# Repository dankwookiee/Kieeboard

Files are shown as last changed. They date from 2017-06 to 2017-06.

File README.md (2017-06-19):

# Readme and Disclaimer

OEM Key profiles were measured off of a set of Vortex PBT Doubleshot 104-Key caps. 

Cherry Key Profiles were estimated off of Cherry Corp. datasheets. 

Files were made using Solidworks 2017. 

This readme shows the keys available in each layout pack, and then walks through the process of modifying dimensions on original Solidworks files. 

Each key in each pack is selectable as a configuration within the solidworks part file. 

**No Measurement or Dimension is Guaranteed to be Accurate or Suitable.**

Absolutely no guarantee is made that these models will perform as expected. Use at your own risk. Models are licensed under Creative Commons Attribution 4.0. Please redistribute and/or modify at will. Please respect the open source nature of these files, and do not use them for personal profit or commercial use. 

**Table of Contents**  *generated with [DocToc](http://doctoc.herokuapp.com/)*

- [Readme and Disclaimer](#)
	- [Layout of Keys in Cherry Pack](#layout-of-keys-in-cherry-pack)
	- [Layout of Keys in OEM Pack](#layout-of-keys-in-oem-pack)
	- [Base dimensions](#base-dimensions)
	- [Angle of Key Front](#angle-of-key-front)
	- [Angle of Key Rear](#angle-of-key-rear)
	- [Front and Rear Key Height](#front-and-rear-key-height)
	- [Shape of Cylindrical Top, Front Sketch](#shape-of-cylindrical-top-front-sketch)
	- [Shape of Cylindrical Top, Rear Sketch](#shape-of-cylindrical-top-rear-sketch)
	- [Wall Thickness](#wall-thickness)
	- [Upright Edge Fillets](#upright-edge-fillets)
	- [Top Edge Fillet](#top-edge-fillet)
	- [Stem Dimensions](#stem-dimensions)
	- [Final Touches/Stabilizer Stems](#final-touchesstabilizer-stems)
	- [Dimensions already included in configurations:](#dimensions-already-included-in-configurations)

## Layout of Keys in Cherry Pack

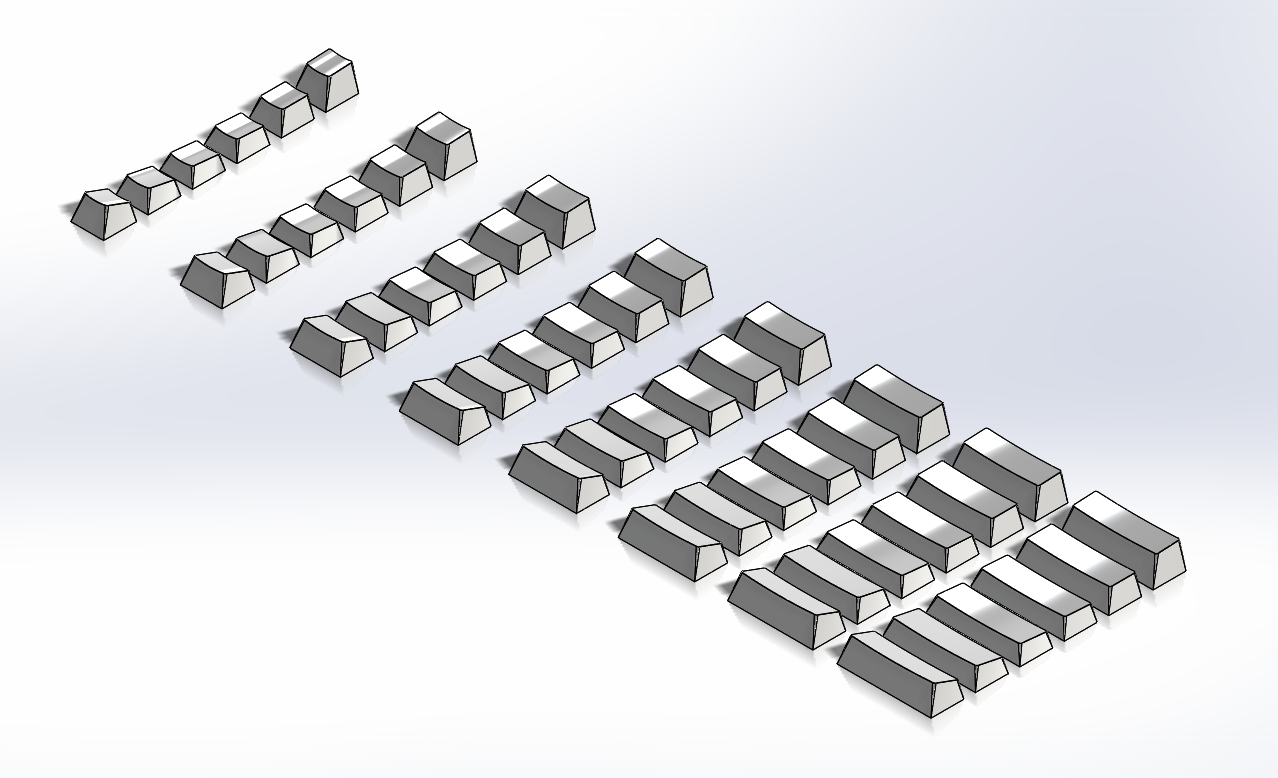
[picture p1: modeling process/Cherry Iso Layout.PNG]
Cherry ISO Layout


## Layout of Keys in OEM Pack

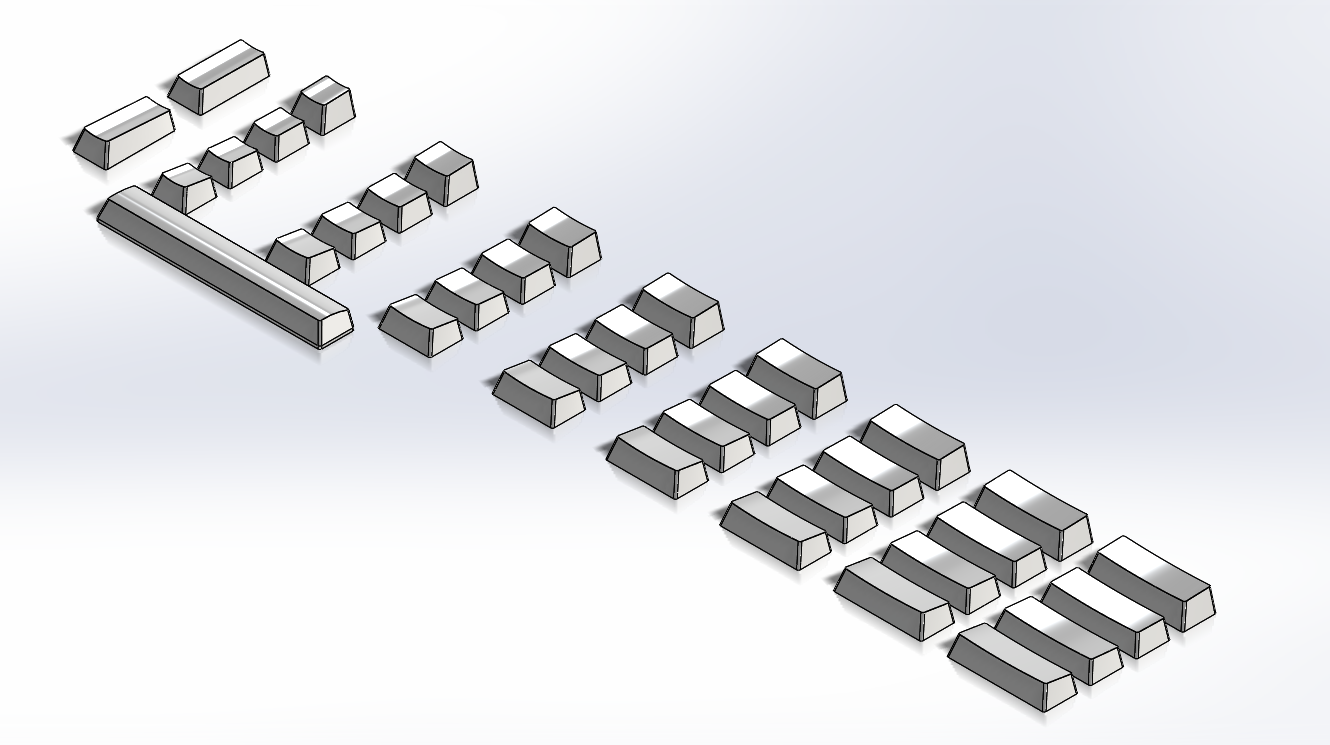
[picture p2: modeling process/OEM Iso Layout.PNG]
OEM ISO Layout


**Modifying Base Dimensions on Wookiee’s Keycaps Files**

## Base dimensions

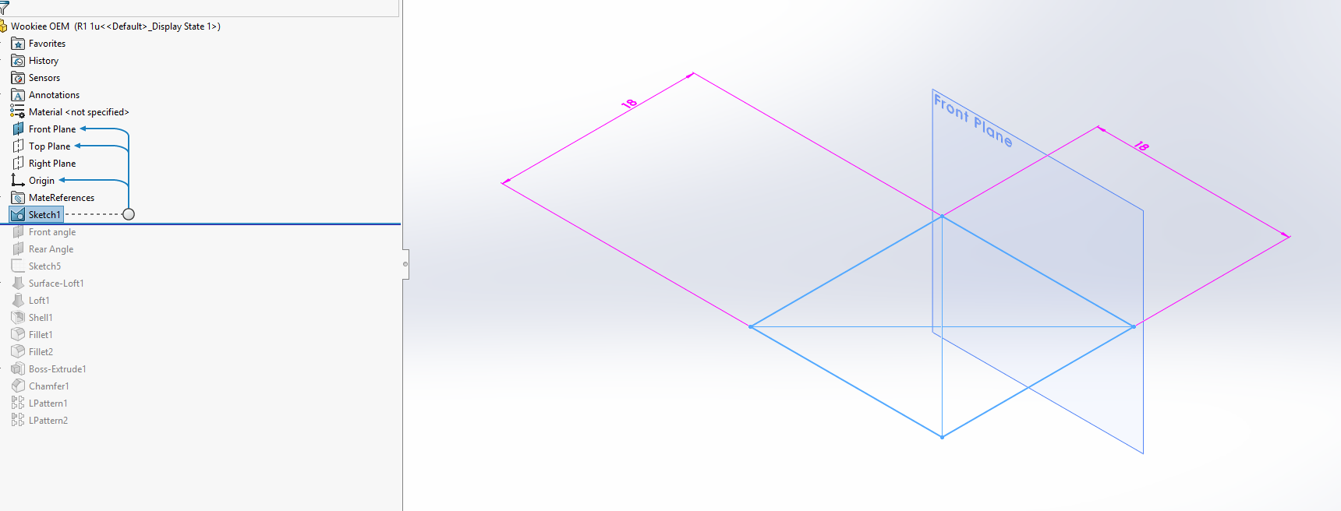
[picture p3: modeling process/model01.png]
Base Dimension Sketch


Base key dimensions are 18x18. Including these dimensions in configurations and design table allows me to switch between any key width and length.

## Angle of Key Front

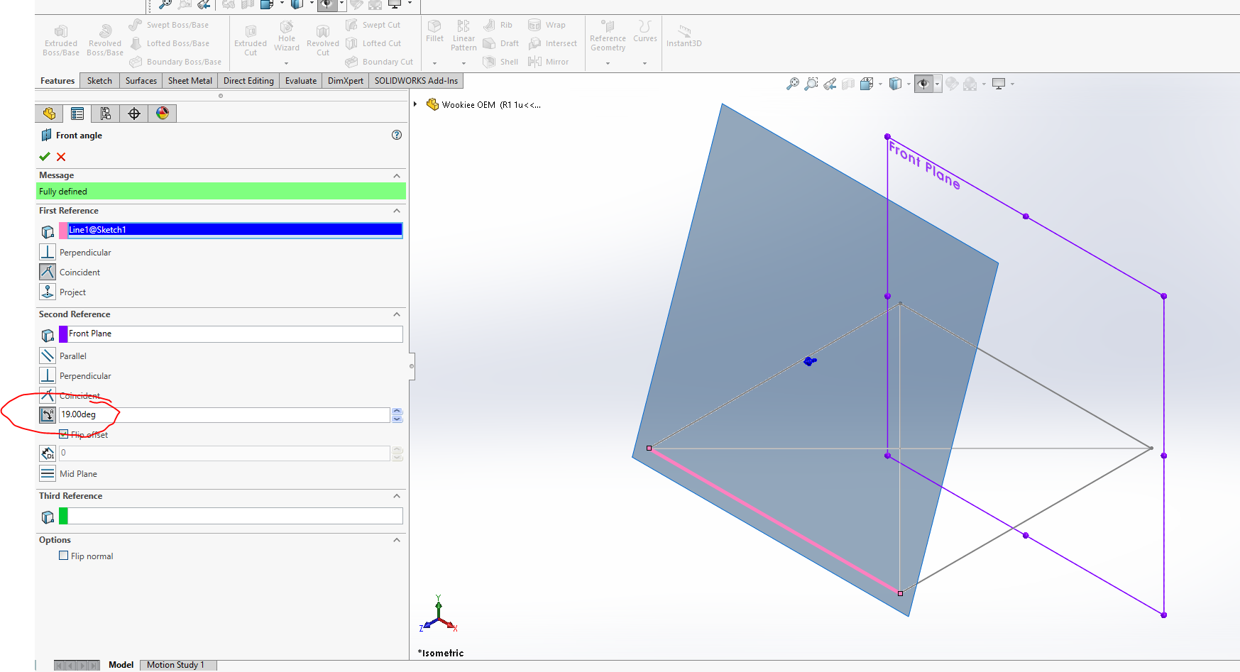
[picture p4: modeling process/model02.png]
Front Angle Sketch


Front plane angle is set coincident with front edge of base, and at an angle. This angle can be adjusted for all configurations, or you can add it to the design table and set different angles for each configuration.
 
## Angle of Key Rear

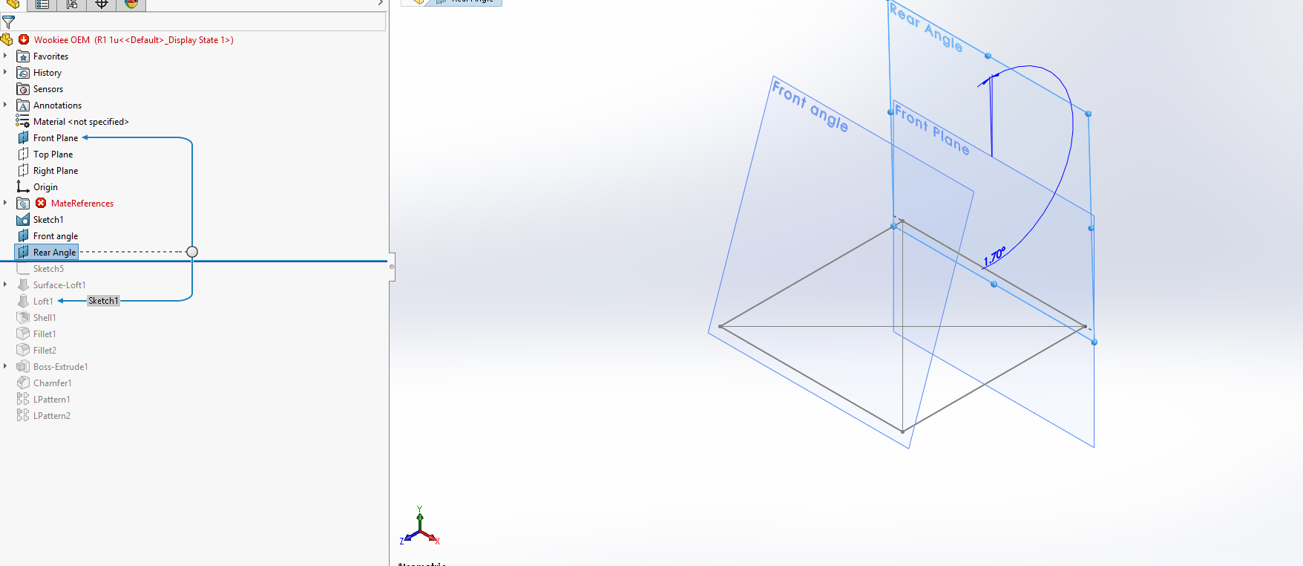
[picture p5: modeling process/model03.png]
Rear Angle Sketch


The angle of the rear plane is set the same way, but references the rear edge of the base sketch. 

## Front and Rear Key Height

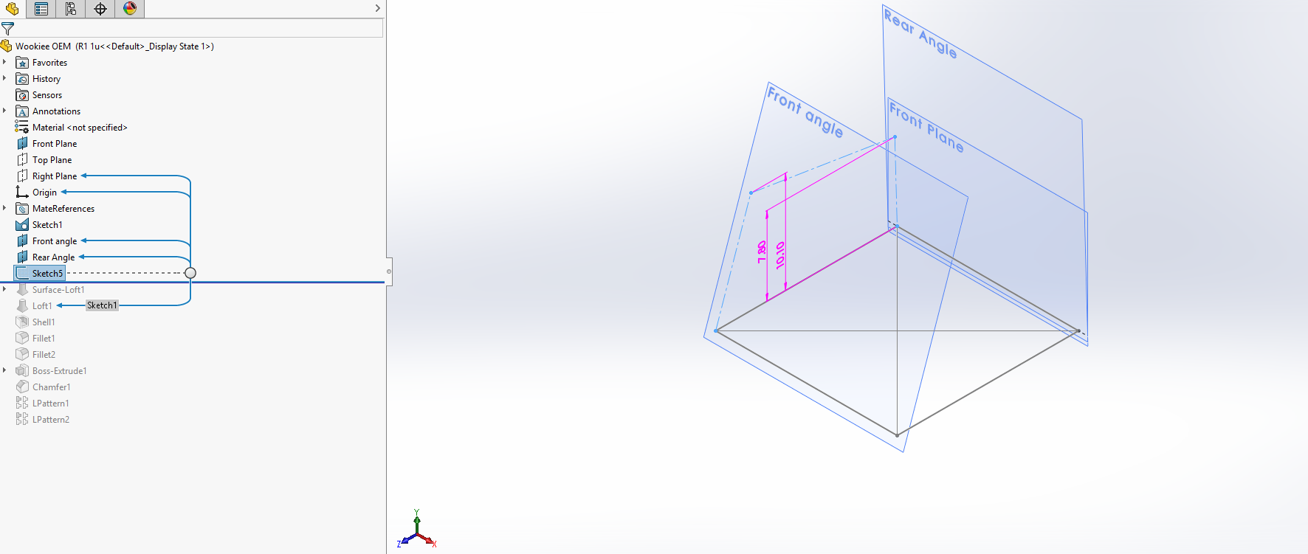
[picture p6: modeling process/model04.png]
Key Height Sketch


The front and rear height of the profile are set using a construction sketch on the right plane. These dimensions are constrained to the front and rear angle planes, and set as distances from the base plane. They are included in the design table and set in each configuration.

## Shape of Cylindrical Top, Front Sketch

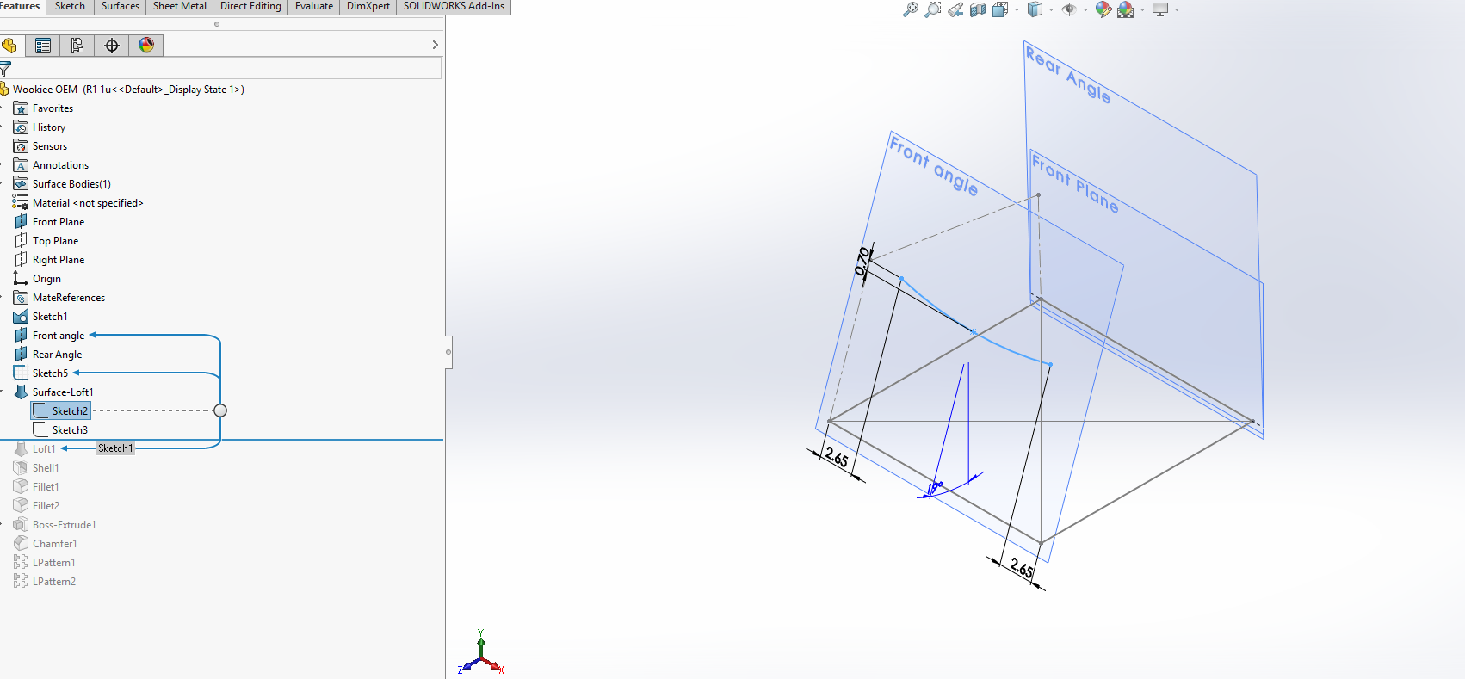
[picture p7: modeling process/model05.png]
Top Front Sketch


The shape of the top of the key is set by an extruded loft between the two angled planes. The front edge is defined on the front angle plane. The width is defined relative to the base, the endpoints are set by the previously sketched profile, and the depth is dimensioned to the midpoint.

## Shape of Cylindrical Top, Rear Sketch

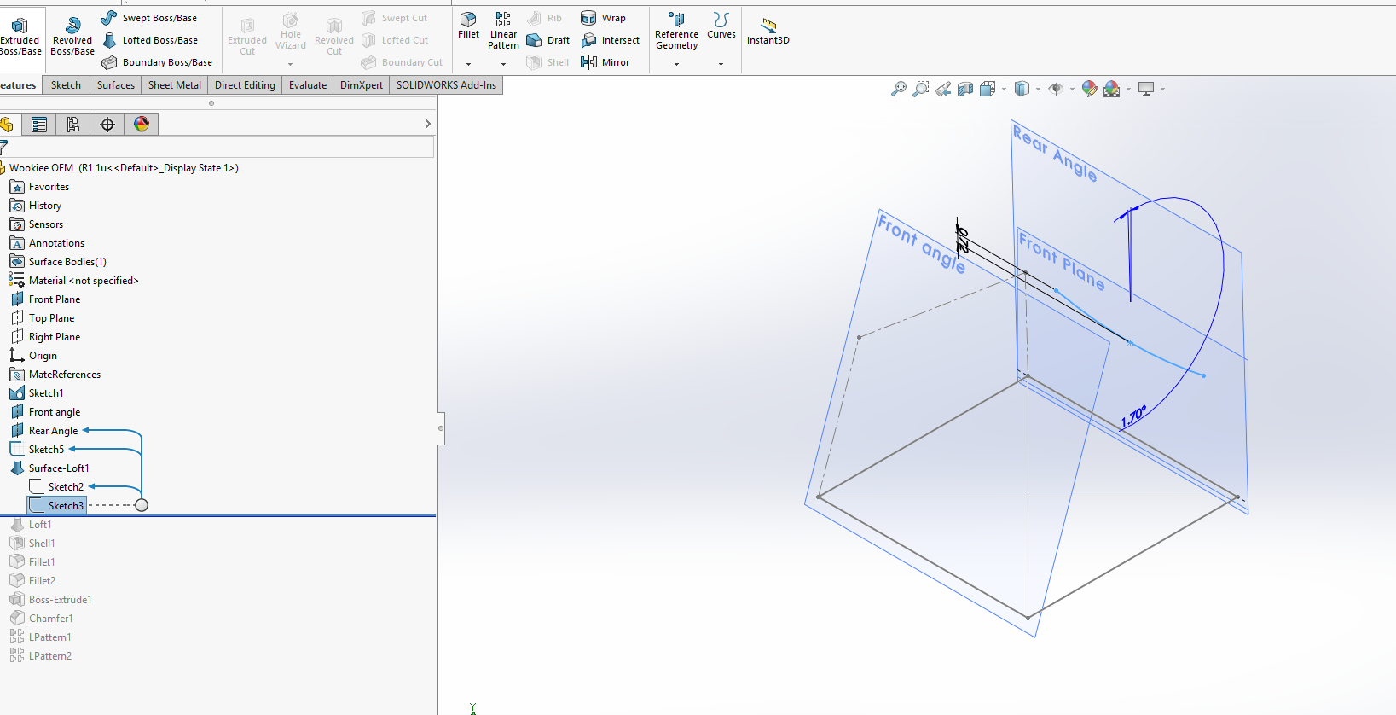
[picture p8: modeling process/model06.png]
Top Rear Sketch


The shape of the top of the key is set by an extruded loft between the two angled planes. The front edge is defined on the front angle plane. The width is defined relative to the base, the endpoints are set by the previously sketched profile, and the depth is dimensioned to the midpoint.

Theoretically, this means you can make the front and rear of the keycap completely different shapes. Just be careful, in the published .sldprt files, changing the shape in one dimension will change it for all dimensions.

## Wall Thickness

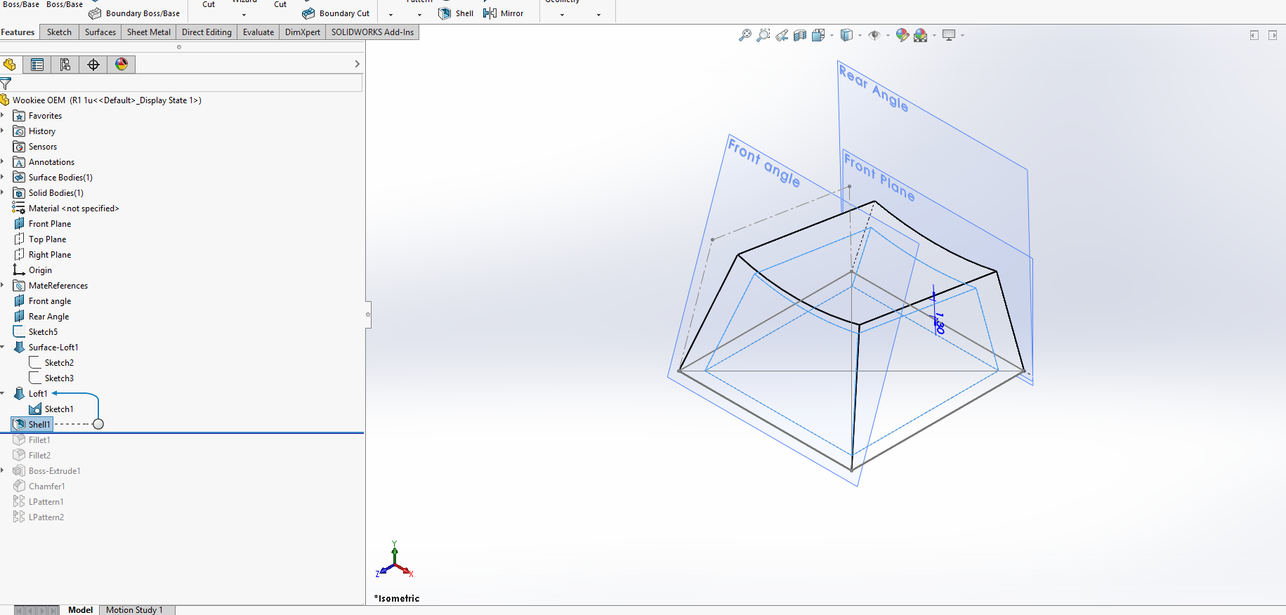
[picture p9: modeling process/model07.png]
Wall Thickness Shell


A loft between the base sketch and the lofted top profile gives the key shape. This is then shelled. The wall thickness is defined by the shell.

## Upright Edge Fillets 

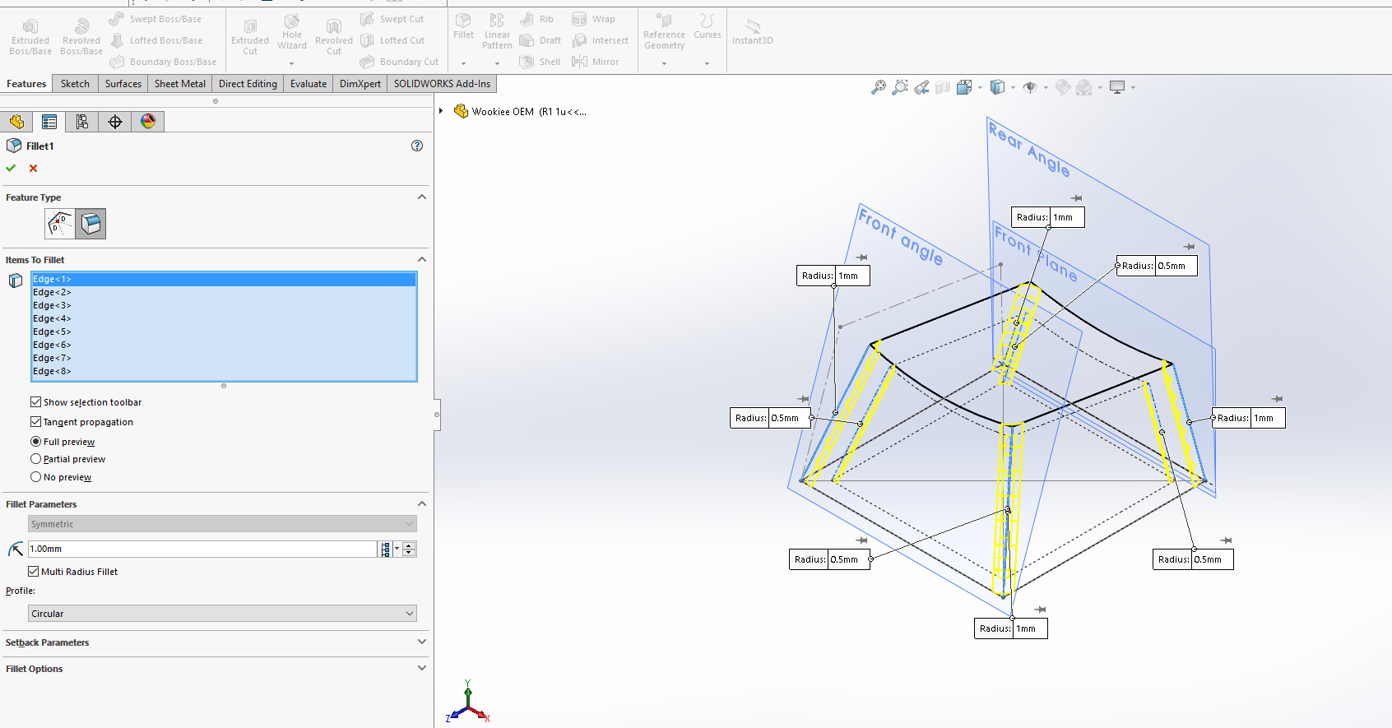
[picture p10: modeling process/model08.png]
Side fillets


The upright edge fillets are set using a multiple radius fillet. Each edge can be edited individually. 

## Top Edge Fillet

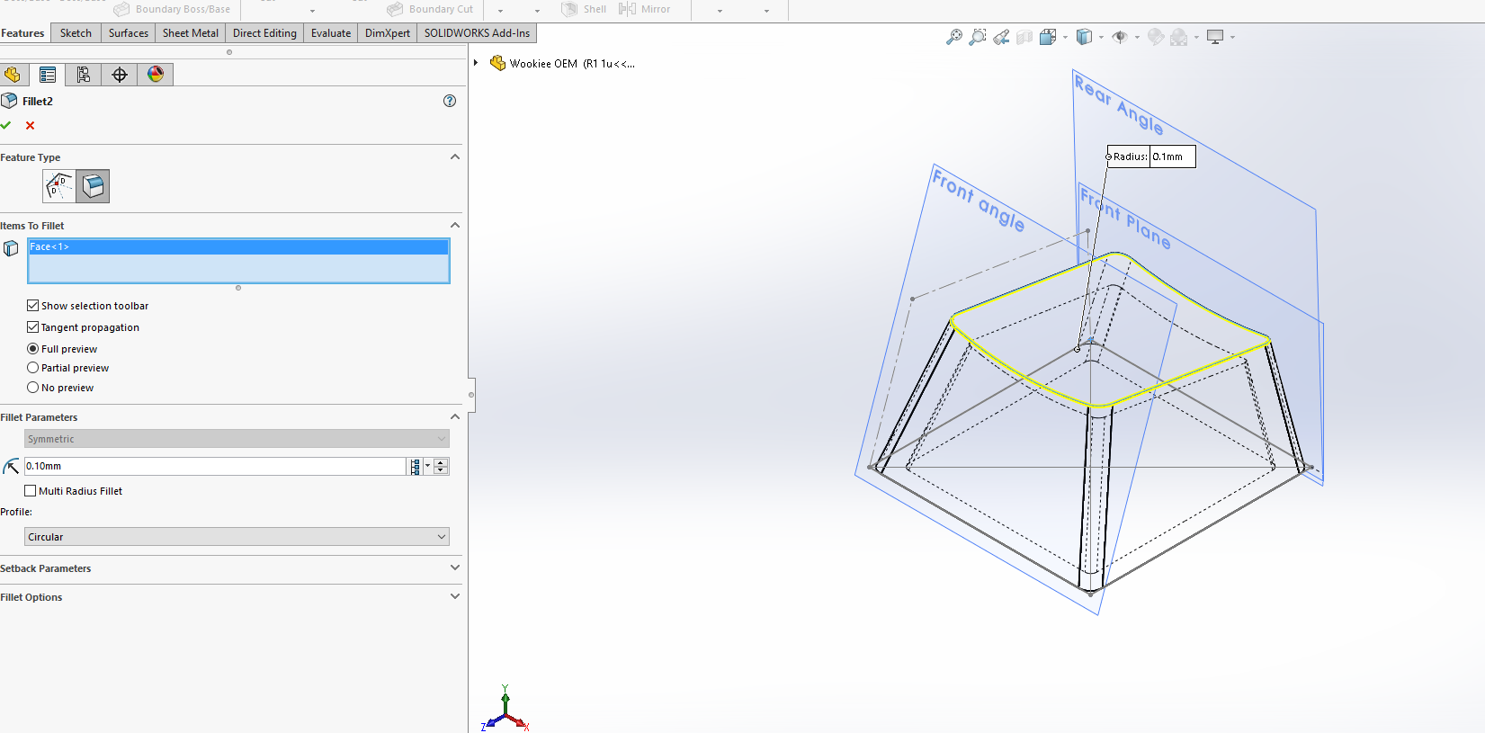
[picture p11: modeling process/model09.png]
Top fillets


The top edge has a tiny fillet put on it. This is for aesthetics and can be suppressed or changed at will.

## Stem Dimensions

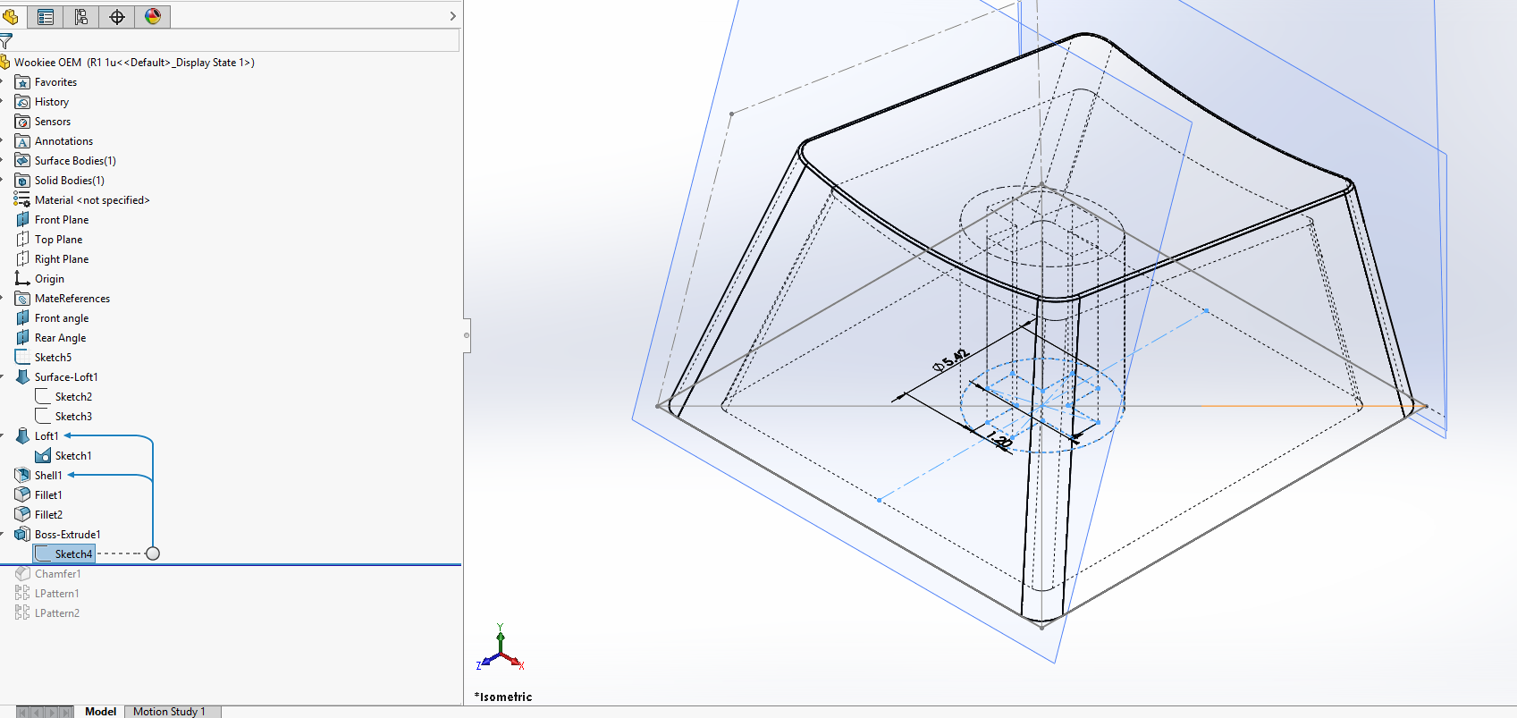
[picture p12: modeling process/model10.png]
Stem Extrusion


The stem shape is defined on the bottom plane, and extruded up to surface to the top surface. These dimensions can be easily changed. I used 1.2mm wide x 4 long for the arms of the key cross.  

## Final Touches/Stabilizer Stems

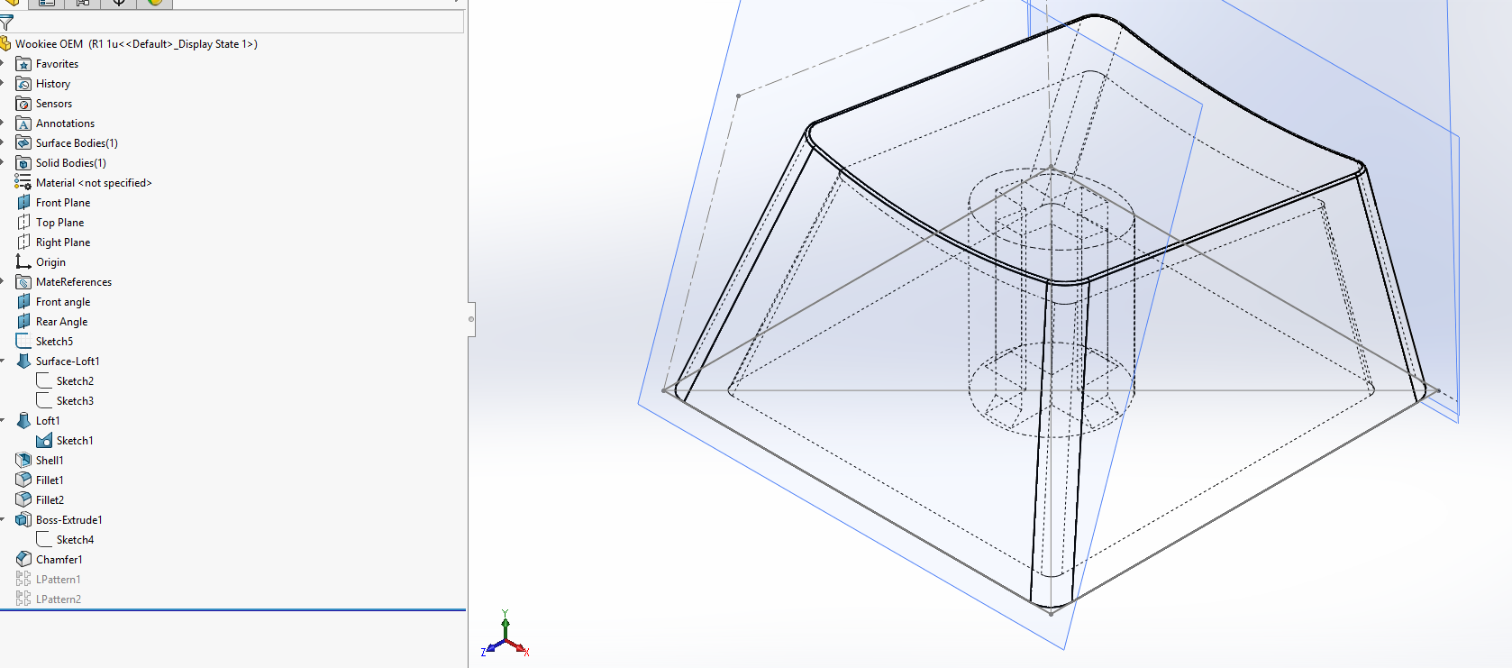
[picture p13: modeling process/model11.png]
Stem Chamfer and Stabs Pattern


The stem opening is chamfered per the Vortex model these were measured from.

Stems for stabilizers are spaced using linear patterns which are suppressed or activated by configuration. Key widths 2u and up have stabilizer stems, shorter key widths do not. 

## Dimensions already included in configurations:

Each SLDPRT file already has configurations for 1u through 2.75u for each row in the profile set. Dimensions used in each configuration are shown in the design table (OEM and Cherry were made with the same key widths for each u). Before editing the SLDPRT file, check and see that you have selected the configuration you want. 

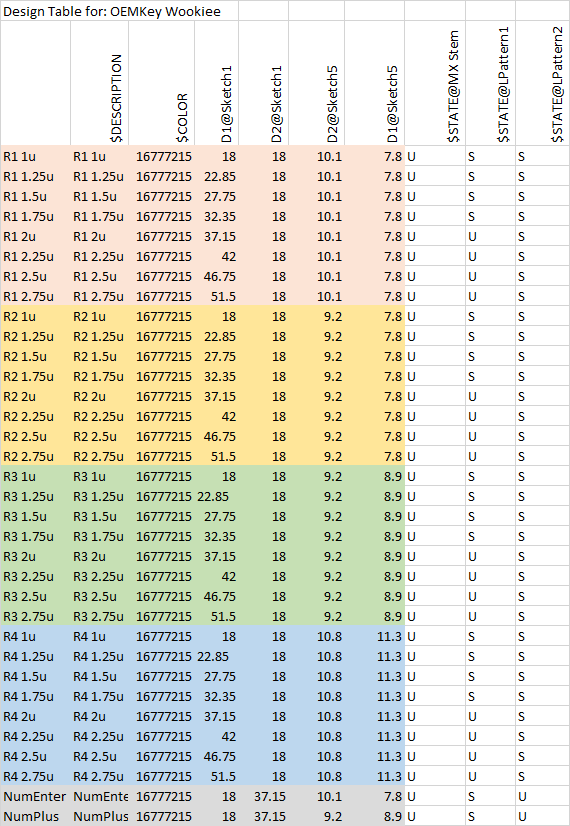
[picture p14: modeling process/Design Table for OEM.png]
Design Table


Thank you for looking! Enjoy.

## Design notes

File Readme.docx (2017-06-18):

06/18/2017

Readme and Disclaimer

OEM Key profiles were measured off of a set of Vortex PBT Doubleshot 104-Key caps.

Cherry Key Profiles were estimated off of Cherry Corp. datasheets.

Files were made using Solidworks 2017.

No Measurement or Dimension is Guaranteed to be Accurate or Suitable.

Absolutely no guarantee is made that these models will perform as expected. Use at your own risk. Models are licensed under Creative Commons Attribution 4.0. Please redistribute and/or modify at will. Please respect the open source nature of these files, and do not use them for personal profit or commercial use.

Modifying Base Dimensions on Wookiee’s Keycaps Files

1. Base Dimensions
2. Angle of Key Front
3. Angle of Key Rear
4. Front and Rear Key Height
5. Shape of Cylindrical Top, Front Sketch
6. Shape of Cylindrical Top, Rear Sketch
7. Wall Thickness
8. Upright Edge Fillets
9. Top Edge Fillet
10. Stem Dimensions
11. Final Touches/Stabilizer Stems.

1. Base dimensions

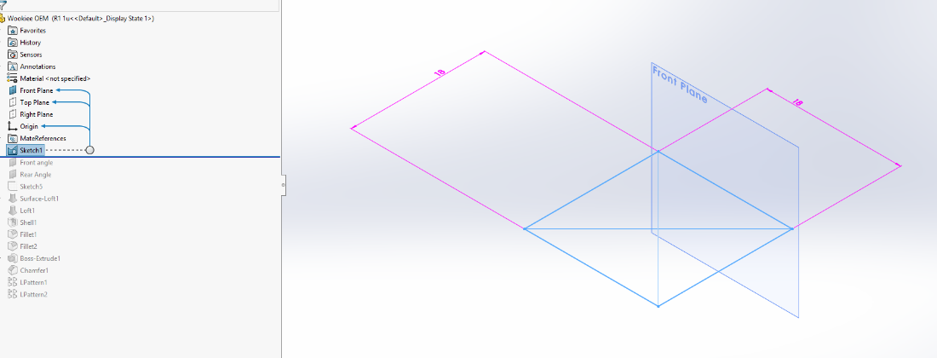
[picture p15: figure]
( 《 【 2 帑 あ 、 型 d56 《 セ n 20 》 》 n 【 ) 山 0 22 00M さ 0 一 帑 も LWV aueld 6 〔 2 言 LieW ロ 」 亠 aueld d01 〔 ・ 【 エ 0 帑 ~ S ア 2E2 ed コ 凸 凸 〔 ed コ 凸 凸 5 」 0 さ as 」 、 」 0 工 扈 u ふ ご 0

Base key dimensions are 18x18. Including these dimensions in configurations and design table allows me to switch between any key width and length.

2. Angle of Key Front

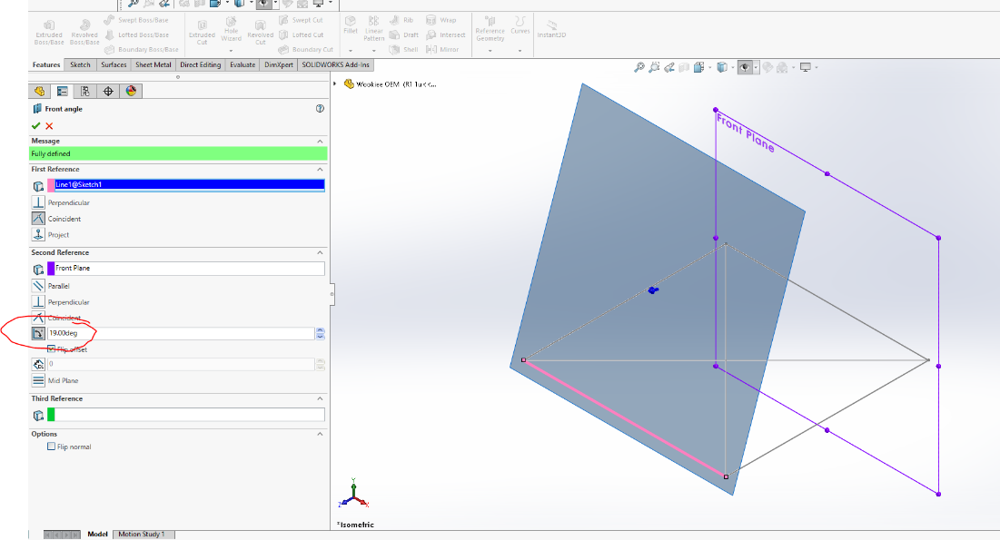
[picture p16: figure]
Extruded Features Revolved Sketch Swept Sossi8ase Lofted Soss;aase Boundary Soss,'Sase Extruded 16 Swept Cut Revolved Lofted Cut Wizard Soundar} Cut Draft Shell Reference Geometry Curves Instant30 Mirror Surfaces Sheet Metal Direct Editing Evaluate DimXpert SOLIDWORKS Add-Ins Wookiee OEM Front ang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

Front plane angle is set coincident with front edge of base, and at an angle. This angle can be adjusted for all configurations, or you can add it to the design table and set different angles for each configuration.

3. Angle of Key Rear

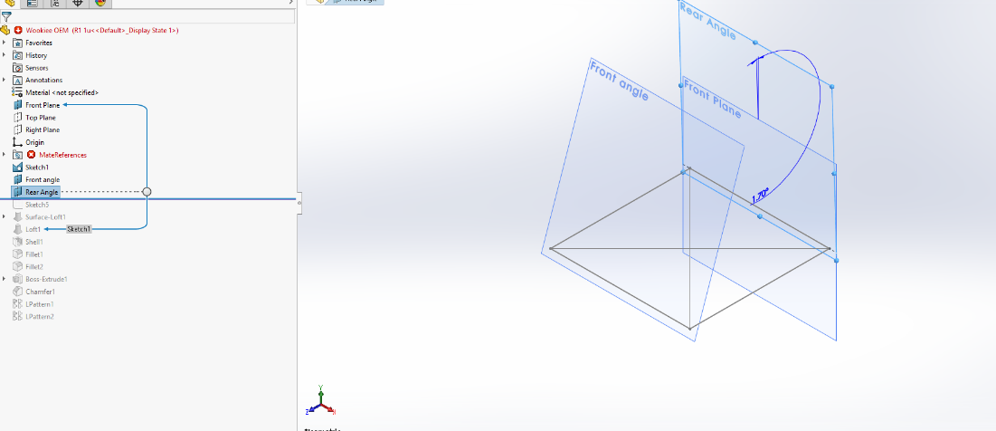
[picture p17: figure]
Machine generated alternative text: Wookiee OEM (RI History Sensors Annotations erial < not specfied> Front Plane Top Plane Right Plane Origin MateReferences Sketchl Front angle Rear Angle - Sketch5 U Surface-Loftl L oft I Ske hl Shelll Filletl Fillet2 Boss-Extrudel Chamferl LPatternI LPattern2 r•kÅ

The angle of the rear plane is set the same way, but references the rear edge of the base sketch.

4. Front and Rear Key Height

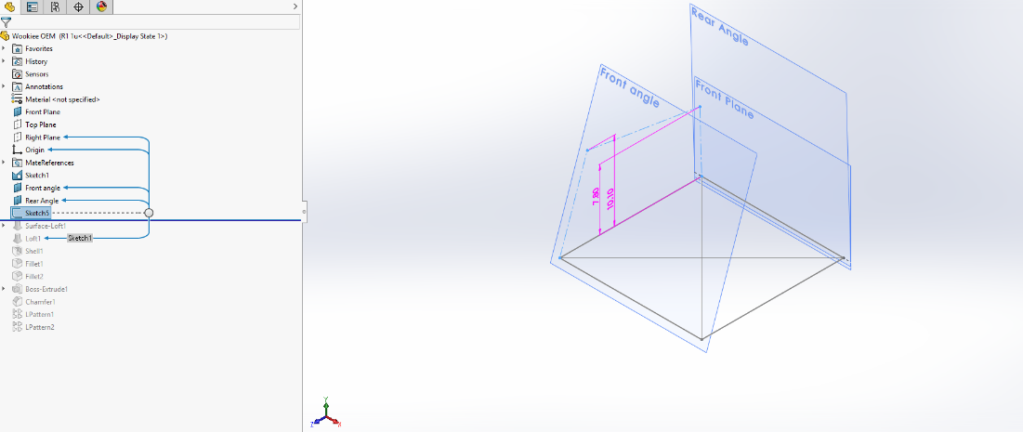
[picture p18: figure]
Machine generated alternative text: Wookiee OEM (RI History Sensors Annotations erial < not specfied> Front Plane Top Plane Right Plane Origin MateReferences Sketchl Front angle Rear Angle C Sketch5 - Surface-Loftl L oft I Shelll Fillet2 Boss-Extrudel Chamferl LPatternI LPattern2 Display State I r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

The front and rear height of the profile are set using a construction sketch on the right plane. These dimensions are constrained to the front and rear angle planes, and set as distances from the base plane. They are included in the design table and set in each configuration.

5. Shape of Cylindrical Top, Front Sketch

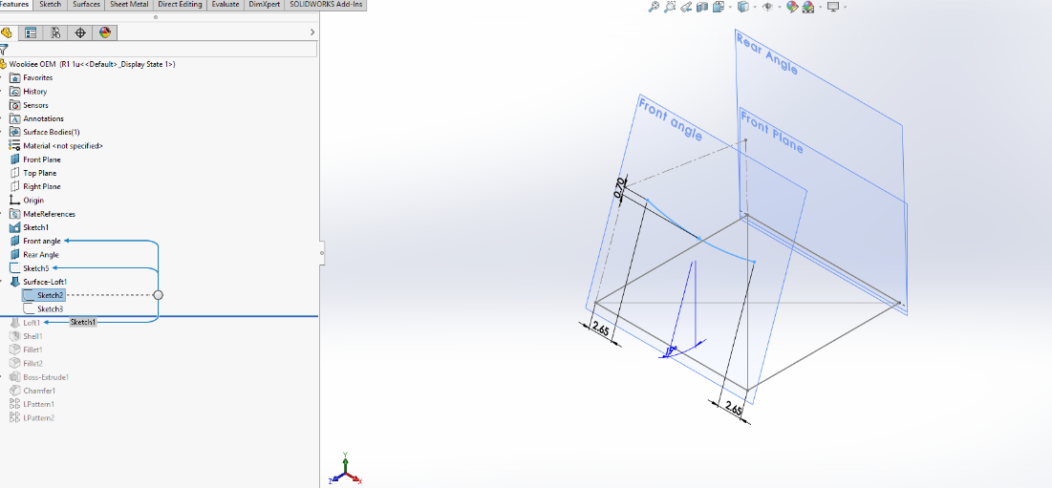
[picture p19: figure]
Machine generated alternative text: res Sketch Surfaces Sheet Metal Direct Editing Qaluate DimXpert Wookiee OEM (RI Favorites History Sensors Annotations Surface Bodies(l) erial < not specfied> Front Plane Top Plane Right Plane Origin MateRef erences Sketchl Front angle Rear Angle C Sketch5 Surfac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

The shape of the top of the key is set by an extruded loft between the two angled planes. The front edge is defined on the front angle plane. The width is defined relative to the base, the endpoints are set by the previously sketched profile, and the depth is dimensioned to the midpoint.

6. Shape of Cylindrical Top, Rear Sketch

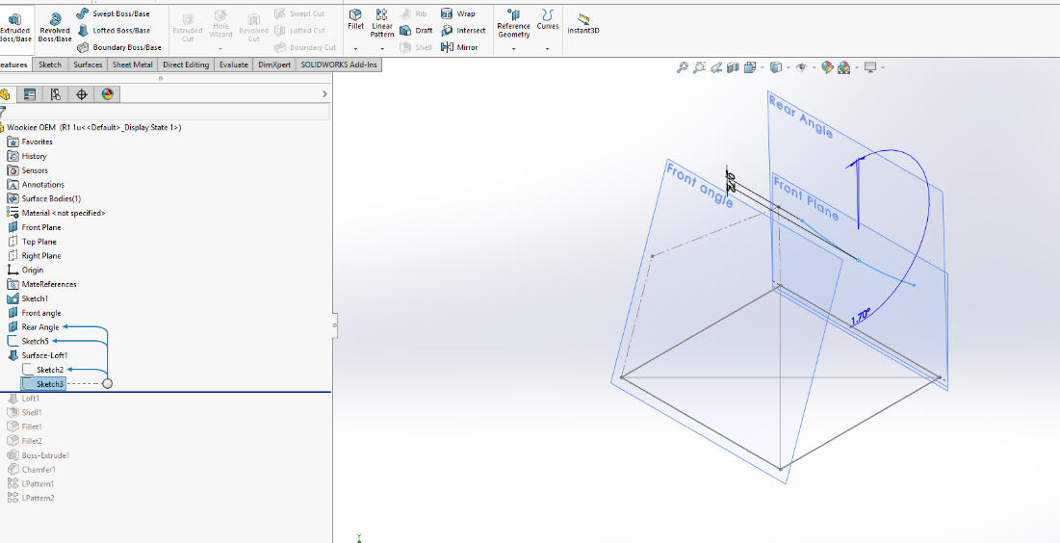
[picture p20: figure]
Machine generated alternative text: Wrap Fillet Extruded ioss/Base res swept aoss,'Base Revolved Lofted 80ss/Base 80ss/Base Boundary 80ss/Base Extruded Swept Cut Revolved Lofted Cut Boundary Cut Linear Pattern Draft Reference Intersect Geometry Mirror Curves Instant3D Wizard Sketch Surfaces Sheet 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

The shape of the top of the key is set by an extruded loft between the two angled planes. The front edge is defined on the front angle plane. The width is defined relative to the base, the endpoints are set by the previously sketched profile, and the depth is dimensioned to the midpoint.

Theoretically, this means you can make the front and rear of the keycap completely different shapes. Just be careful, in the published .sldprt files, changing the shape in one dimension will change it for all dimensions.

7. Wall Thickness

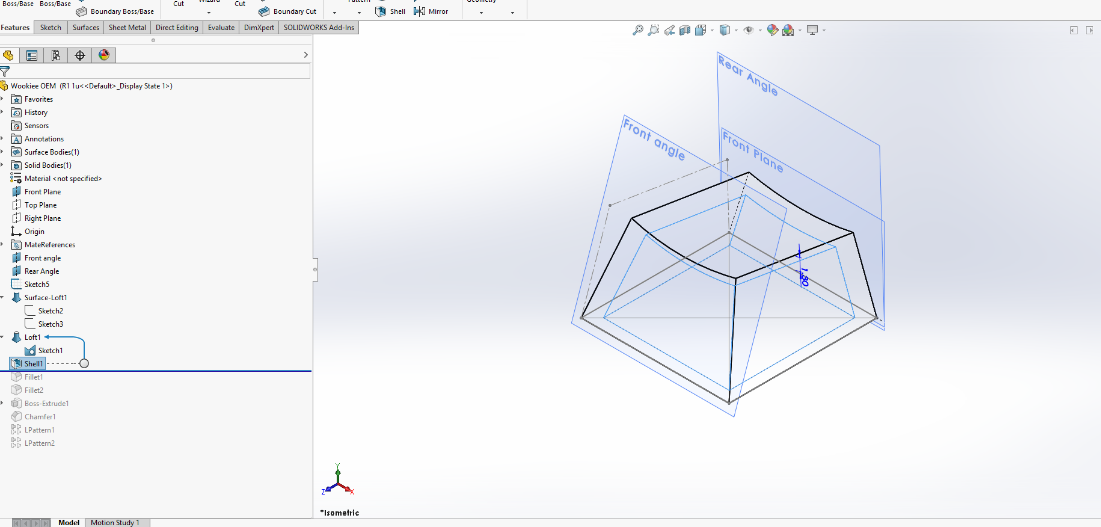
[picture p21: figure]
Machine generated alternative text: 80ss/Base Features 80ss/Base Boundary 80ss/Base Sketch Surfaces Sheet Metal Direct Editing Evaluate e Boundary Cut DimXpert SOLIDWORKS Add-ins Shell Mirror Wookiee OEM (RI History Sensors Annotations Surface Bodies(l) Solid Bodies(l) erial < not specfied> Front 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

A loft between the base sketch and the lofted top profile gives the key shape. This is then shelled. The wall thickness is defined by the shell.

8. Upright Edge Fillets

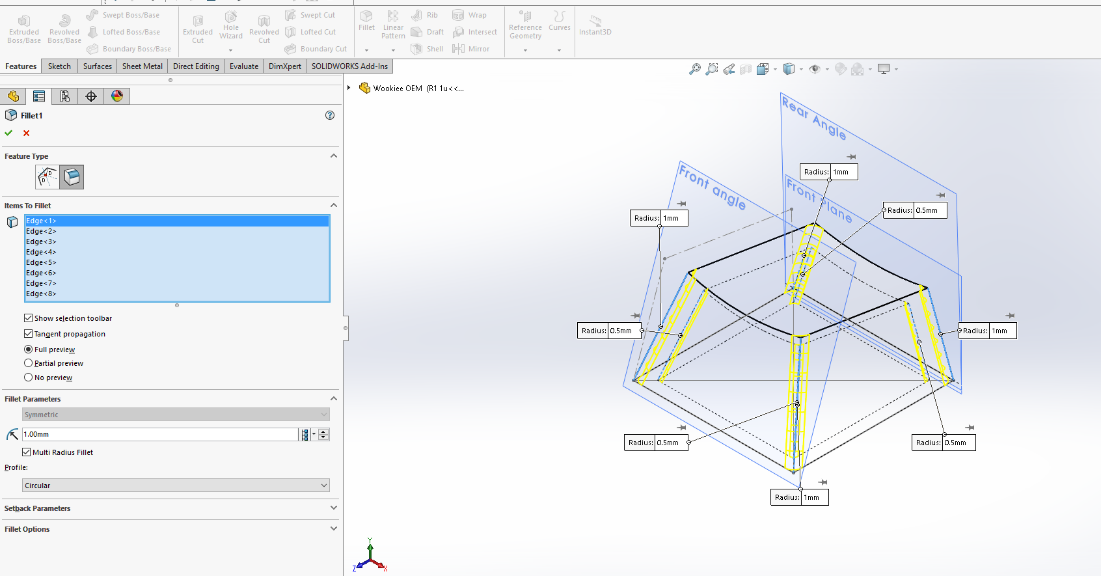
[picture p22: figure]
Swept Soss;aase Lofted Soss;aase Extruded Features Filleti Feature Rens To Revolved Sketch Extruded Revolved Wizard 16 Swept Cut Lofted Cut Boundary Cut Draft Shell Reference Intersect Geometry Mirror Curves Instant30 Boundary Soss;aase Surfaces Sheet Metal Direct Editing Evaluate DimXpert SOLIDWO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

The upright edge fillets are set using a multiple radius fillet. Each edge can be edited individually.

9. Top Edge Fillet

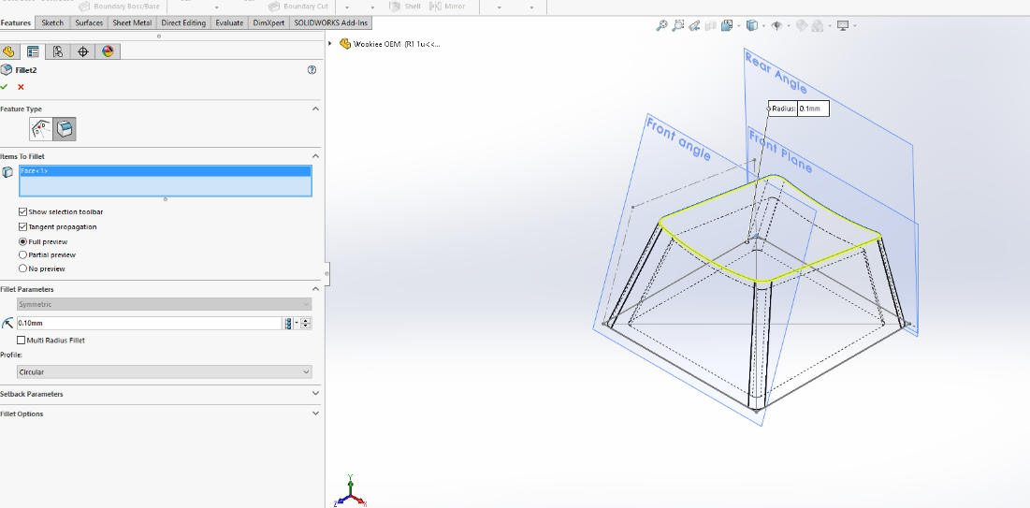
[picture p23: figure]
Machine generated alternative text: Boundary Soss,'Sase Surfaces Sheet Metal Direct Editing Features Sketch Fillet2 Feature Ty pe To Fillet Evaluate Soundar} Cut DimXpert SOLIDWORKS Add-ins Q 31 Shell Mirror Wookiee OEM Radius: 0.1 mm Z] Shcn,v selection toolbar Z] Tangent propagation @ Full previ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

The top edge has a tiny fillet put on it. This is for aesthetics and can be suppressed or changed at will.

10. Stem Dimensions

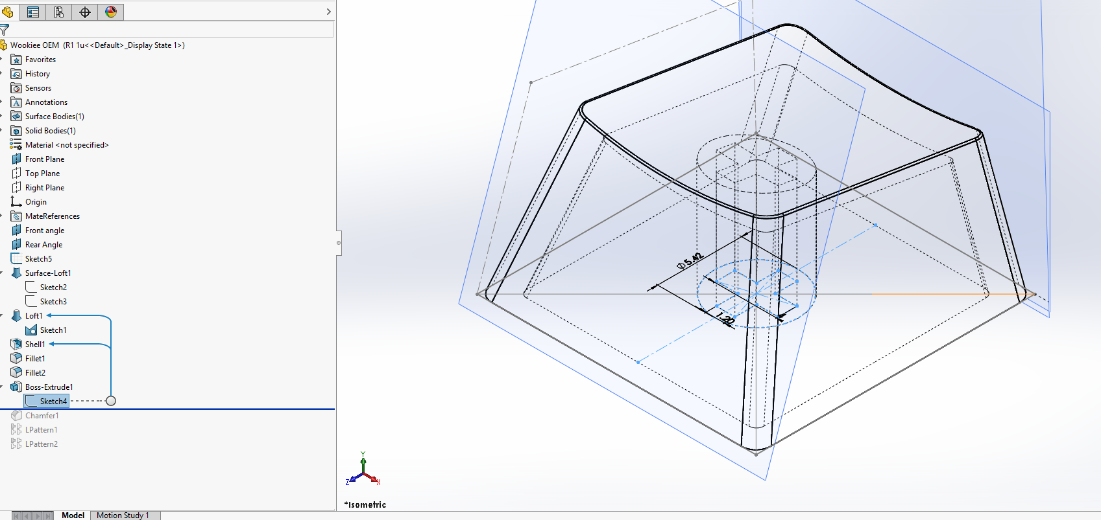
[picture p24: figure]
Machine generated alternative text: Wookiee OEM (RI Favorites History Sensors Annotations Surface Bodies(l) Solid Bodies(l) erial < not specfied> Front Plane Top Plane Right Plane Origin MateRef erences Front angle Rear Angle C Sketch5 Surface-Loftl C Sketch2 C Sketch3 Sketchl Shelli Fillet2 Boss-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

The stem shape is defined on the bottom plane, and extruded up to surface to the top surface. These dimensions can be easily changed. I used 1.2mm wide x 4 long for the arms of the key cross.

11. Final Touches/Stabilizer Stems

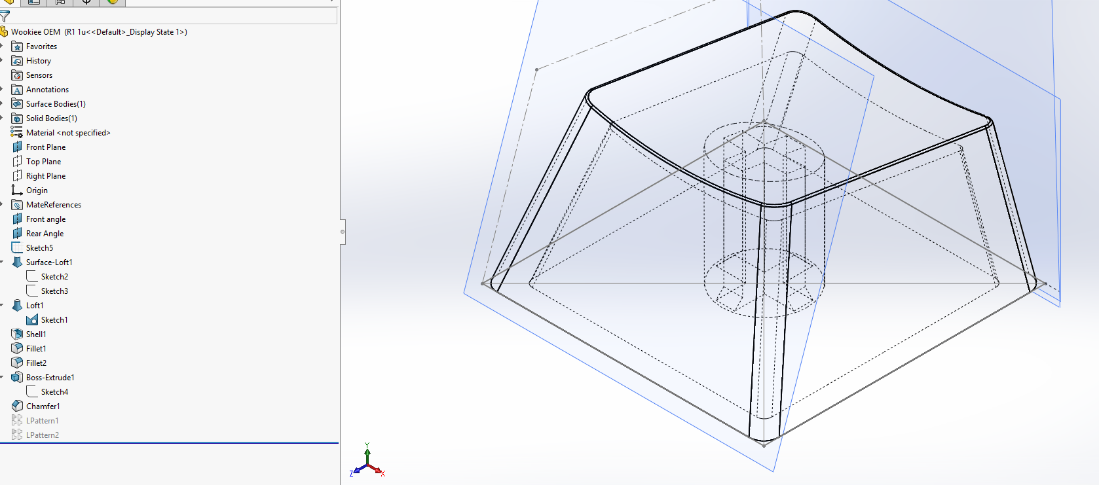
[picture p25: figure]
Machine generated alternative text: Wookiee OEM (RI Favorites History Sensors Annotations Surface Bodies(l) Solid Bodies(l) erial < not specfied> Front Plane Top Plane Right Plane Origin MateRef erences Front angle Rear Angle C Sketch5 Surface- Loftl C Sketch2 C Sketch3 Sketchl Shelli Fillet2 Boss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

The stem opening is chamfered per the Vortex model these were measured from.

Stems for stabilizers are spaced using linear patterns which are suppressed or activated by configuration. Key widths 2u and up have stabilizer stems, shorter key widths do not.

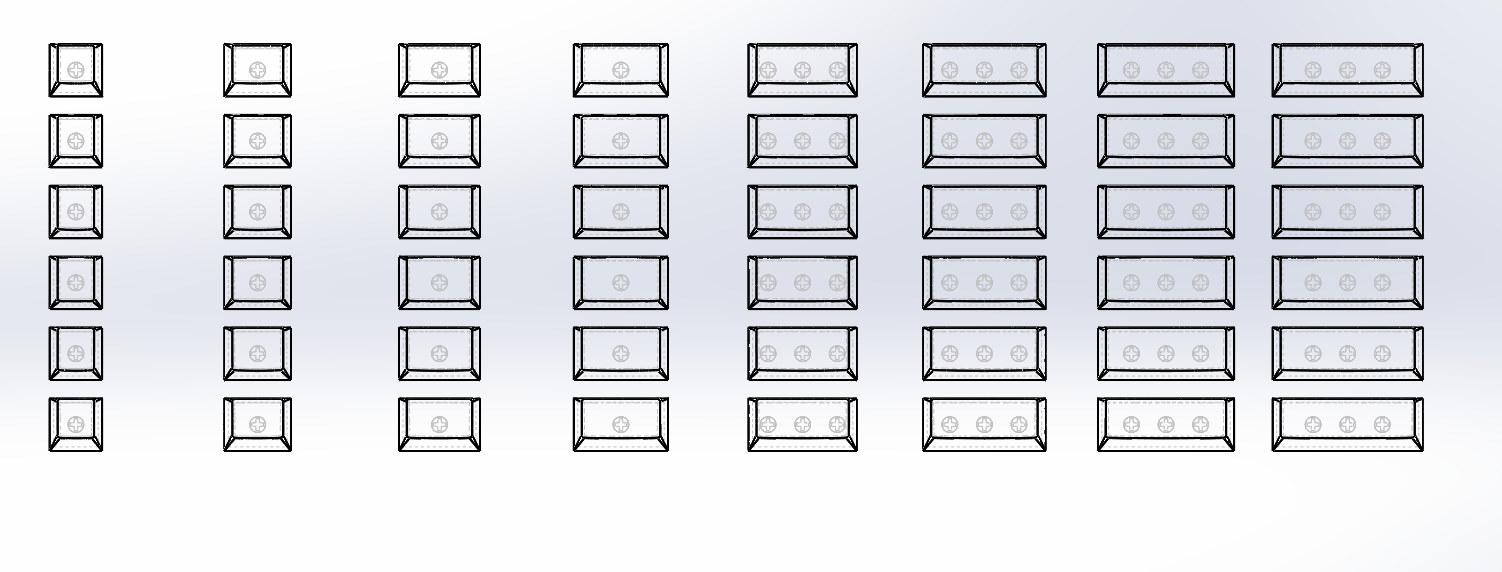
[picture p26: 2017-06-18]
Cherry Top Hidden.PNG

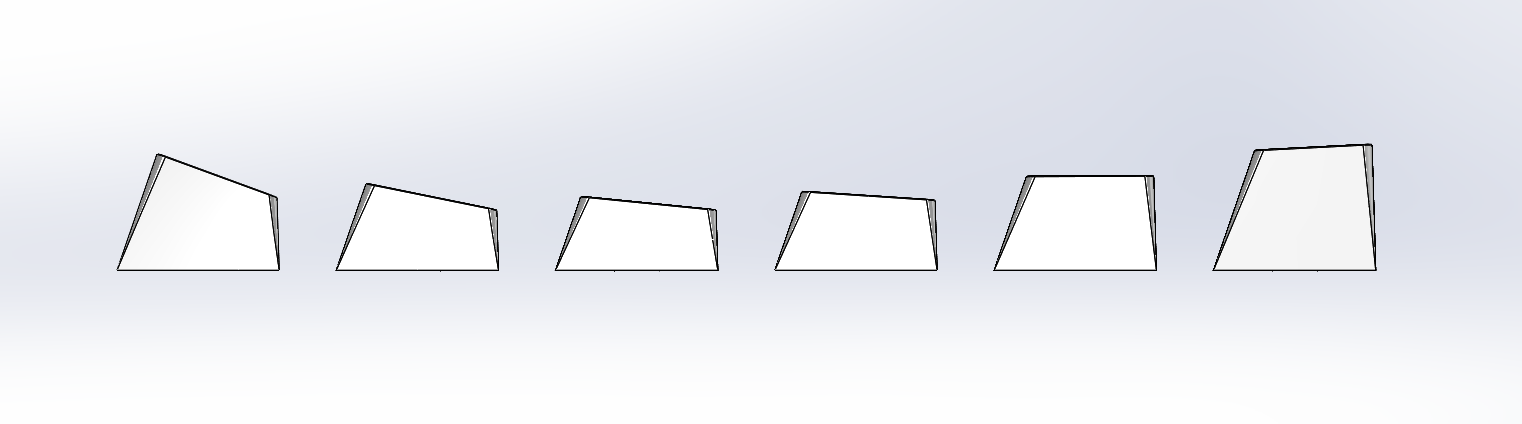
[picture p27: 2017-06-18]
Cherry Profile Right.PNG

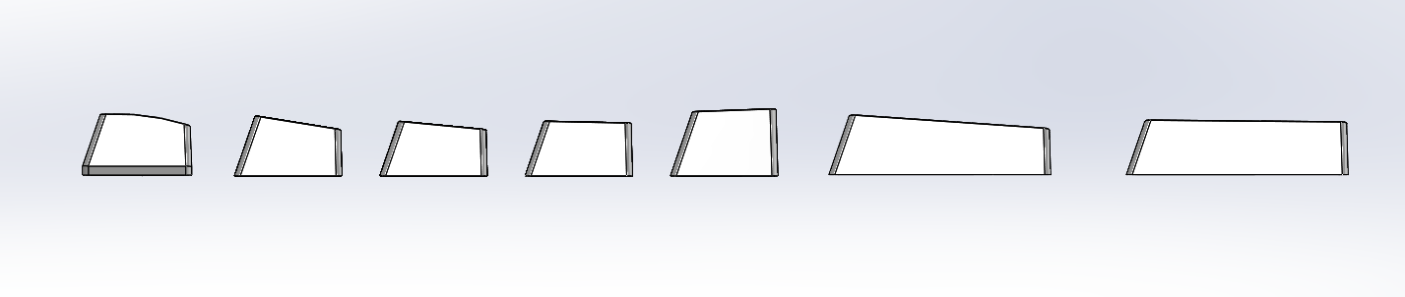
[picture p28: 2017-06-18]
OEM Profile Right.PNG

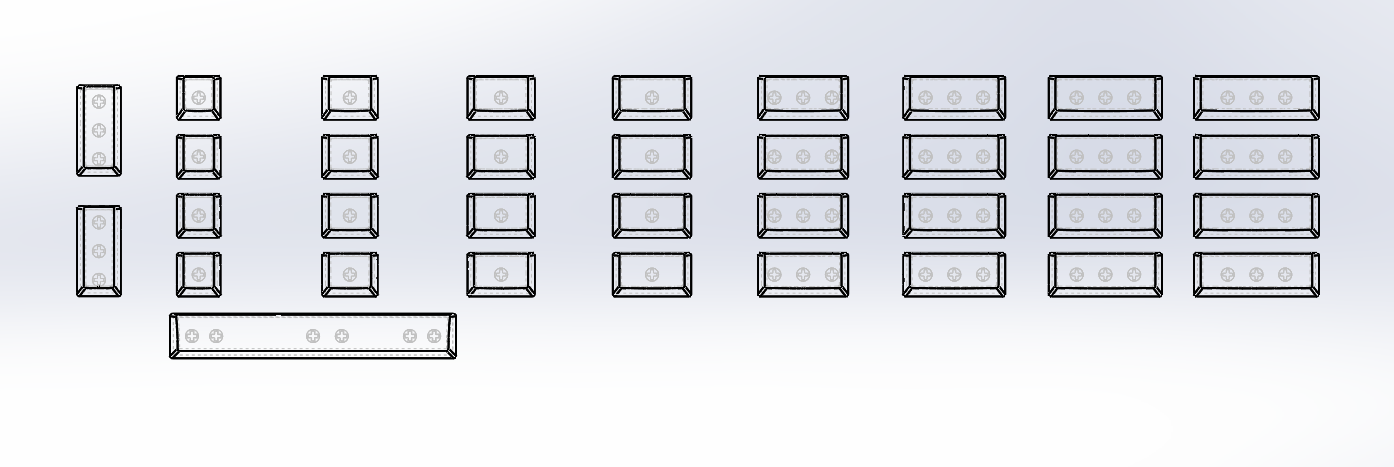
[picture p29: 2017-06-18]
OEM Top Hidden.PNG

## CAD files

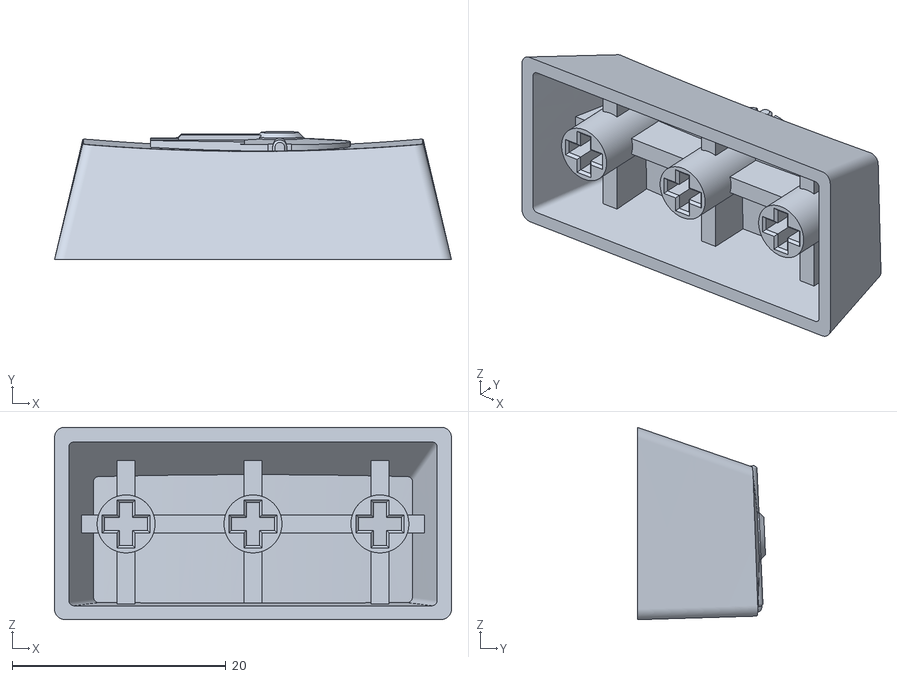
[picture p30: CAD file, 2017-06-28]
Custom STL/Wookiee Falcon BKSP Rev2b.STL
37.1 x 12.0 x 18.0

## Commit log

2017-06-18 Add files via upload
    Deleted duplicate STL files.
2017-06-28 Millenium Falcon OEM Backspace
    [Wookiee Falcon BKSP Rev2b.STL]
2021-09-07 Adding vintage spec sheet for MX Keycaps
    Contains 3D dimensions and technical data for MX switches and keycaps, both cylindrical and standard.
